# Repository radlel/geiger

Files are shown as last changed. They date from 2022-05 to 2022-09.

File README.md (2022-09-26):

# Geiger-Muller counter

This project describes complete process of designing and constructing
Geiger-Muller counter device.

## Counter final form:

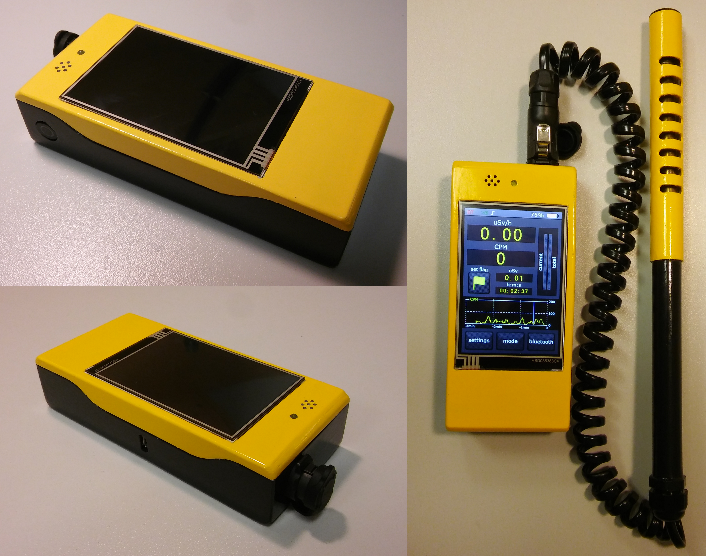
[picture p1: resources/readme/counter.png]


## Features:
- Current radiation measurement
- Background radiation measurement
- Total absorbed radiation dose measurement
- High radiation levels warnings
- 3.5" touch screen
- Advanced data presentation
- Dedicated android application for storing measured data
- Bluetooth connection
- 3D printed cover
- Measurements modes
- LED and buzzer notifications
- Li-ion cell

## Scientific background
A Geiger–Müller counter is device used for detecting and measuring ionizing radiation.
It detects radiation such as alpha particles, beta particles, and gamma rays.
Detection is possible thanks to ionization effect produced in a Geiger–Müller tube.



Between anode (_A_) and cathode (_K_) there is high voltage applied (typically 400–900V),
which enables tube operation. Tube is filled with an inert gas such as helium, neon,
or argon at low pressure. When a particle or photon of incident radiation goes through the tube,
it makes the gas conductive by ionization and the tube briefly conducts electrical charge.
The ionization is considerably amplified within the tube by the Townsend discharge effect to
produce an easily measured detection pulse. Pulses are counted by electronic device and
recalculated to radiation in Sv/Rem, according to tube characteristic.

## Data presented on Counter screen:

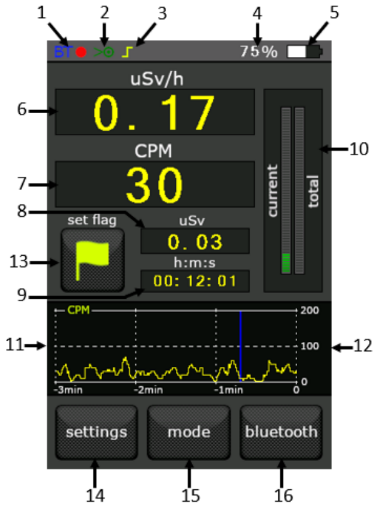
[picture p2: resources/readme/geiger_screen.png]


1. Bluetooth connection status
2. Touch screen status
3. Background radiation subtraction status
4. Screen brightness
5. Battery level
6. Radiation level (uSv/h, uRem/h)
7. Counts per minute (CPM)
8. Total dose absorbed (uSv, uRem)
9. Measurement time
10. Radiation level warning bars
11. CPM chart from last 3 minutes
12. Adjustable CPM chart range
13. Button for adding markers to measurement
14. Button opening settings submenu
15. Button opening measurement modes submenu
16. Button opening bluetooth connection submenu

## Electronics

### _Geiger-Muller tube amplification_
The most crucial circuit of whole device is detection and amplification of
Geiger-Muller tube pulses. Detection is performed by tube SBM-20.
Between its anode and cathode there is high 400V voltage applied.
Pulses amplification is done by two bipolar transistors BC547B.
Output signal is connected to uC input pin with interrupts handling implemented.
Additionally, every pulse is notified by LED and buzzer connected to the circuit.

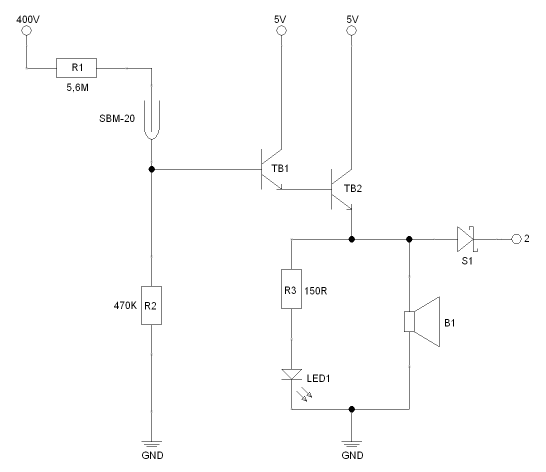
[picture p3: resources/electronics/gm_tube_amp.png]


### _Power supply_
Device is powered by Li-ion cell Panasonic NCR 18650B if capacity 3400mAh.
For charging and cell protection it is used circuit TP4056.
To ensure stable voltage for the device there is also DC-DC converter
used which generates output voltage 5V regardless battery voltage.
As mentioned already, Geiger-Muller tube requires 400V for proper operation.
For this reason there is another DC-DC transformer used which accepts 5V
as input and generates 400V output.

There are other electronic elements and circuits integrated into device.
The full electrical diagram is available _[here](resources/electronics/ee_complete.png)_.

## Atmega software
Main Counter logic is written in C based Arduino language.
Used libraries:
- Arduino
- Nextion
- SoftwareSerial

Interrupts are used to detect Geiger-Muller tube pulses as well as button press.

In _loop()_ function there is periodic execution of:
- Radiation measurement and calculations
- Touch screen actions handling
- Power button actions handling
- Bluetooth connection and communication
- Battery voltage monitoring
- Warnings handling

Communication with touch screen is carried out via UART. Data to be displayed is sent periodically. Touch screen actions are obtained with use of polling mechanism. Every actions has its own unique id which triggers certain action in uC.

Complete Atmega source code is available _[here](Atmega/Atmega_328P.ino)_.

## Geiger RL2018PI application
This Android application was created in Android Studio/Java.

It's main task is to establish connection with Geiger-Muller counter via Bluetooth, collect measurement data
and generate output .xls file for later analysis.

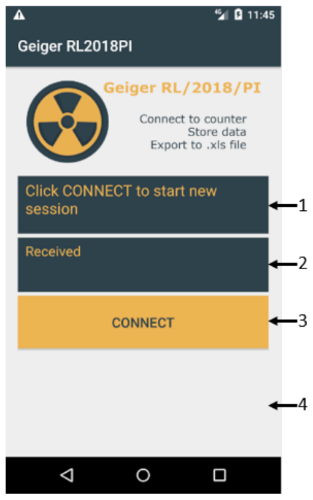
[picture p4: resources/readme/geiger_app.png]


1. Connection status
2. Data received from Geiger-Muller counter
3. Button to connect/disconnect 
4. List of paired bluetooth devices

Source code is available _[here](Android/Mobile.apk)_.

## Device cover
Main device cover was designed in SolidWorks and then printed using 3D printer.
Cover was split into two parts - bottom and top. The design included holes for Geiger-Muller tube cable,
charging cable, buzzer, LED and power button. Also, supports for internal elements were added.

After assembling Counter, bottom and top cover parts are held together by hooks.

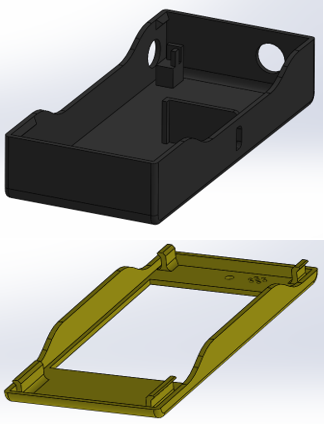
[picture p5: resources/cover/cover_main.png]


Device cover was smoothed and pained for yellow and dark grey colors.

Geiger-Muller tube SBM-20 was placed in separate cover made from two PVC pipes. For better handling covers were
connected by spiral cable. Project files and more photos are available _[here](cover)_ and _[here](resources/cover)_.

## Counter characteristics
_TODO_

## License
[MIT](https://choosealicense.com/licenses/mit/)

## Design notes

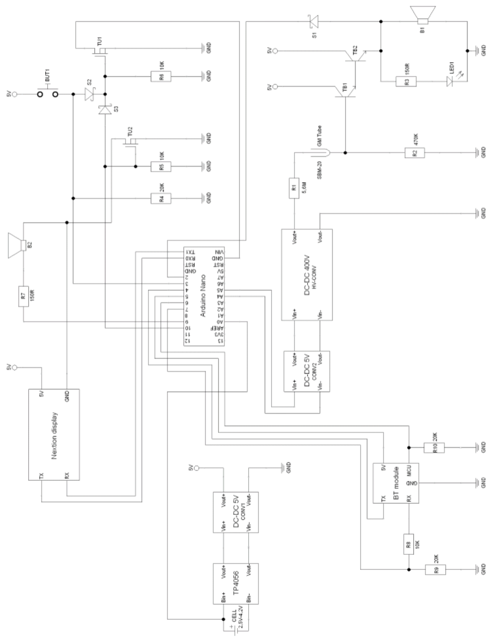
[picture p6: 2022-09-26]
resources/electronics/ee_complete.png

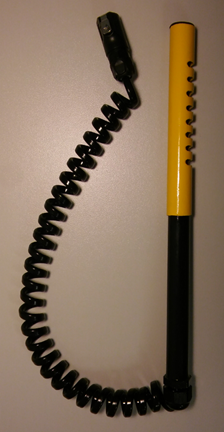
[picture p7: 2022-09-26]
resources/cover/cover_tube.png

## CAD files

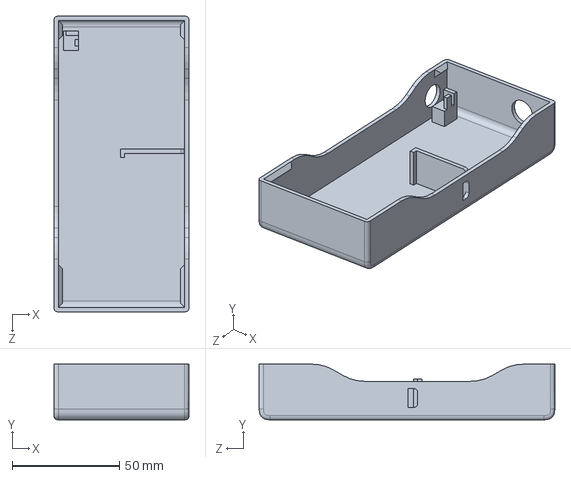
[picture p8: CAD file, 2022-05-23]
cover/Part_bottom.SLDPRT
63.0 x 26.0 x 138.0 mm

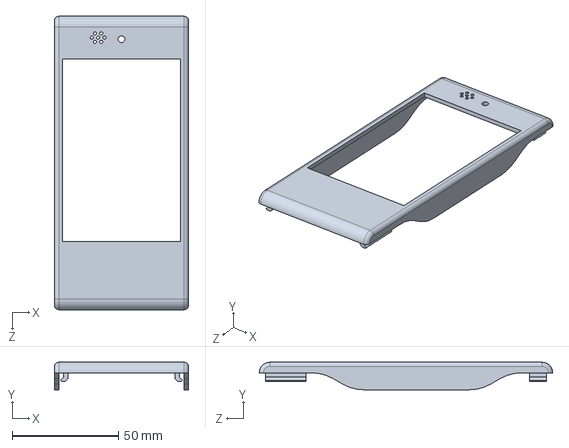
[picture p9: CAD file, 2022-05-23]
cover/Part_top.SLDPRT
63.0 x 13.0 x 138.0 mm

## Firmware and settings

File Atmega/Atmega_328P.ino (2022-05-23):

#include "Arduino.h"
#include "Nextion.h"
#include "SoftwareSerial.h"


#define DET 2
#define BUT 3
#define bluetoothP 5
#define PIR 6
#define POW 10
#define ALARM_PIN 9
#define CONV_GND 18
#define CONV_VCC 19
#define CEL A0

#define TB_S 6
#define CPMtouSvpH 0.0057
#define COUNTtouSv (CPMtouSvpH / 60)
#define TON 1150
#define TOF 3000


enum alarm_source {
  BT_CON_BROKEN,
  LOW_BATTERY,
  HIGH_CURR_RADIATION
  HIGH_TOTAL_RADIATION
};


volatile unsigned short ssc = 0;
unsigned short tab[TB_S] = {0};
unsigned short t_i = 0;
unsigned long tt;
unsigned long t_sec = 0;
unsigned long CPM = 0;
unsigned long uSv = 0;
unsigned short plot_rg = 200;
unsigned long background_val = 0;
unsigned long source_val = 0;
long measure_result = -1;
String flag_name = "";
SoftwareSerial bluetoothS (4, 7);

NexProgressBar ncl (0, 8, "j2");
NexVariable r1 (0, 22, "R1");
NexVariable r2 (0, 23, "R2");
NexVariable r3 (0, 24, "R3");
NexVariable r4 (0, 25, "R4");
NexVariable r5 (0, 26, "R5");
NexVariable r6 (0, 27, "R6");
NexVariable y1 (0, 36, "y1");
NexVariable y2 (0, 37, "y2");
NexVariable t4 (0, 54, "t4");
NexVariable t5 (0, 54, "t5");
NexVariable nex_flag (0, 56, "flag_str");
NexVariable touch (0, 38, "touch");
NexVariable help (0, 49, "help");

boolean start_patr_2 = true;
boolean bluetooth = false;
boolean pair = false;
boolean bt_finish = false;
boolean rem = false;
boolean background = false;
boolean measure = false;
boolean reset = false;
boolean alarm = false;
boolean usv_range_end = false;

volatile boolean button = false;


void setup() {
	pinMode(BUT, INPUT);
	pinMode(POW, OUTPUT);
	pinMode(bluetoothP, OUTPUT);
	pinMode(PIR, INPUT);
	pinMode(ALARM_PIN, OUTPUT);

	pinMode(CONV_GND, OUTPUT);
	pinMode(CONV_VCC, OUTPUT);

	attachInterrupt(0, excDet, RISING);
	attachInterrupt(1, excBut, RISING);
	nexInit();
	bluetoothS.begin(9600);

	delay(TON);
	digitalWrite(POW, HIGH);
	digitalWrite(CONV_GND, LOW);
	digitalWrite(CONV_VCC, HIGH);
	start_p1();
}

void loop() {
	check_nex_touch();
	if(!reset) proc_and_print_results();
	if(bluetooth) bluetooth_send();
	if(bluetooth) bluetooth_read();
	if(pair) if_paired();
	if(measure) measure();
	if(button) check_button();
	set_cell_level();
	if(alarm) alarm_sound();
	if(reset) reset();
}


void excDet() { ssc ++; }

void excBut() { if(t_sec > 0 && !reset) button = true; }


void start_p1() {
	tt = millis();
	while(t_i < TB_S - 1) {
		if(millis() - tt >= 1000) {
			tab[t_i] = ssc;
			ssc = 0;
			tt = millis();
			t_i ++;
			if(t_i == 1) ncl.setValue(map(no_bigger_than(analogRead(CEL), 860), 512, 860, 0, 100));
		}
	}
	tt = millis();
}

void start_p2() {
	sendCommand("sys0=1");
	sendCommand("tsw 255,1");
	sendCommand("plot.en=1");
	sendCommand("p2.pic=56");
	start_patr_2 = false;
}

void reset() {
	for(int i = 0; i < TB_S; i++) tab[i] = 0;
	ssc = 0;
	t_i = 0;
	t_sec = 0;
	CPM = 0;
	uSv = 0;
	plot_rg = 200;
	background_val = 0;
	source_val = 0;
	measure_result = -1;
	start_patr_2 = true;
	bluetooth = false;
	digitalWrite(bluetoothP, LOW);
	pair = false;
	rem = false;
	background = false;
	measure = false;

	start_p1();
	reset = false;
}

void check_nex_touch() {
	static unsigned long ttl = millis();
	char flag_buf[31] = {0};

	if(millis() - ttl >= 100) {
		ttl = millis();
		uint32_t n;
		touch.getValue(&n);

		switch(n) {
		case 0:		
			if(measure_result != -1) measure_result = -1;
			break;
		case 1:		
			rem = true;
			if(background_val > 0) proc_and_set(background_val, t4, "t4");
			if(source_val > 0 && source_val > background_val && background) proc_and_set(source_val - background_val, t5, "t5");
			else if(source_val > 0 && source_val <= background_val && background) t5.setText("0.00");
			else if(source_val > 0 && !background) proc_and_set(source_val, t5, "t5");
			sendCommand("click func,1");
			break;
		case 2:		
			rem = false;
			if(background_val > 0) proc_and_set(background_val, t4, "t4");
			if(source_val > 0 && source_val > background_val && background) proc_and_set(source_val - background_val, t5, "t5");
			else if(source_val > 0 && source_val <= background_val && background) t5.setText("0.00");
			else if(source_val > 0 && !background) proc_and_set(source_val, t5, "t5");
			sendCommand("click func,1");
			break;
		case 9:		
			reset = true;
			sendCommand("rest");
			break;
		case 11:	
			measurement(&background_val, n);
			break;
		case 12:	
			measurement(&source_val, n);
			break;
		case 18:	
			background = true;
			if(source_val > 0 && source_val > background_val) proc_and_set(source_val - background_val, t5, "t5");
			else if(source_val > 0 && source_val <= background_val) t5.setText("0.00");
			sendCommand("click func,1");
			break;
		case 19:	
			background = false;
			if(source_val > 0) proc_and_set(source_val, t5, "t5");
			sendCommand("click func,1");
			break;
		case 31:	
			digitalWrite(bluetoothP, HIGH);
			pair = true;
			sendCommand("click func,1");
			break;
		case 32:	
			bt_finish = true;
			digitalWrite(bluetoothP, LOW);
			bluetooth = false;
			sendCommand("click func,1");
			break;
		case 33:	
			bluetooth = false;
			pair = false;
			digitalWrite(bluetoothP, LOW);
			sendCommand("help.val=32");
			sendCommand("click func,1");
			break;
		case 41:	
			memset(flag_buf, 0, sizeof(flag_buf));
			nex_flag.getText(flag_buf, sizeof(flag_buf));
			flag_name = String(flag_buf);
			if(flag_name != "") sendCommand("click func,1");
			break;
		case 100:	
			plot_rg = 100;
			sendCommand("click func,1");
			break;
		case 200:
			plot_rg = 200;
			sendCommand("click func,1");
			break;
		case 500:
			plot_rg = 500;
			sendCommand("click func,1");
			break;
		case 1000:
			plot_rg = 1000;
			sendCommand("click func,1");
			break;
		case 2000:
			plot_rg = 2000;
			sendCommand("click func,1");
			break;
		case 5000:
			plot_rg = 5000;
			sendCommand("click func,1");
			break;
		case 10000:
			plot_rg = 10000;
			sendCommand("click func,1");
			break;
		}
	}
}

void proc_and_print_results() {
	if(millis() - tt >= 1000) {
		unsigned short ssc_t;

		tab[t_i] = ssc_t = ssc;
		ssc = 0;
		tt = millis();
		if(t_i < TB_S - 1) t_i ++;
		else t_i = 0;

		CPM = 0;
		for(int i = 0; i < TB_S; i++) CPM += tab[i];
		CPM *= (60 / TB_S);
		long dif = 0;
		if(background) {
			dif = CPM - background_val;
			if(dif < 0) dif = 0;
			r2.setValue(dif);
		}
		else r2.setValue(CPM);

		if(background) proc_and_set(background_val >= CPM ? 0 : CPM - background_val, r1, "r1");
		else proc_and_set(CPM, r1, "r1");

		static boolean too_big_uSvph = false;
		if(CPM * CPMtouSvpH >= 1.17 && !too_big_uSvph) {
			alarm_show(3);
			too_big_uSvph = true;
		}

		if(too_big_uSvph && CPM * CPMtouSvpH < 1.17) {
			sendCommand("A3.val=2");
			too_big_uSvph = false;
		}

		if(!usv_range_end) {
			uSv += ssc_t;
			proc_and_set(uSv, r3, "r3");
		}

		static boolean too_big_uSv = false;
		if(uSv * COUNTtouSv >= 9.32  && !too_big_uSv) {
			too_big_uSv = true;
			alarm_show(4);
		}

		r4.setValue(t_sec);
		t_sec ++;

		if(CPM * CPMtouSvpH <= 0.39) r5.setValue(int(map_f(CPM * CPMtouSvpH, 0.0, 0.39, 0, 44)));
		else 			r5.setValue(int(map_f(no_bigger_than(CPM * CPMtouSvpH, 5.0), 0.39, 5.0, 44, 100)));

		if(uSv * COUNTtouSv <= 9.32) r6.setValue(int(map_f(uSv * COUNTtouSv, 0, 9.32, 0, 61)));
		else 		    r6.setValue(int(map_f(no_bigger_than_f(uSv * COUNTtouSv, 27.96), 9.32, 27.96, 61, 100)));

		static boolean ch = true;
		if(ch) y1.setValue(map(no_bigger_than(CPM, plot_rg), 0, plot_rg, 1, 80));
		else   y2.setValue(map(no_bigger_than(CPM, plot_rg), 0, plot_rg, 1, 80));
		ch = !ch;

		if(start_patr_2) start_p2();
	}
}

void proc_and_set(unsigned long value, NexVariable nt, String nex_name) {
	char buf[10] = {0};
	String str = "";

	if(nex_name == "r1") {
		if (!rem || (rem && value * CPMtouSvpH < 100.0)) str = String(double(value * CPMtouSvpH * (rem ? 100 : 1)));
		else str = String(long(value * CPMtouSvpH * 100 + 0.5));
	} else if(nex_name == "r3") {
		if(uSv * COUNTtouSv >= 100000.0) {
			str = ">100mSv";
			usv_range_end = true;
		} else if(rem && value * COUNTtouSv >= 1000.0) str = String(long(value * COUNTtouSv * 100 + 0.5));
		else str = String(double(value * COUNTtouSv * (rem ? 100 : 1)));
	} else if(nex_name == "t4" || nex_name == "t5") {
		str = String(double(value * CPMtouSvpH * (rem ? 100 : 1)));
	}

	str.toCharArray(buf, sizeof(buf), 0);
	nt.setText(buf);
}

void measure() {
	static boolean start = true;
	static unsigned long temp = 0;
	static unsigned long ttl1, ttl2;
	if(start) {
		ttl1 = ttl2 = t_sec;
		start = false;
		temp = 0;
	}

	if(t_sec - ttl1 == TB_S ) {
		for(int i = 0; i < TB_S; i++) temp += tab[i];
		ttl1 = t_sec;
	}

	if(t_sec - ttl2 >= 600) {
		measure_result = temp / 10;
		measure = false;
		start = true;
	}
}

void measurement(unsigned long *v, uint32_t n) {
	if(measure == false && measure_result == -1) measure = true;
	if(measure_result > -1) {
		*v = measure_result;
		sendCommand("click func,1");
		if	    (n == 12 && source_val > background_val && background) proc_and_set(source_val - background_val, t5, "t5");
		else if (n == 12 && source_val <= background_val && background) t5.setText("0.00");
		else if (n == 12 && !background) proc_and_set(source_val, t5, "t5");
		else if (n == 11) {
			proc_and_set(background_val, t4, "t4");
			if(background && source_val > 0 && source_val > background_val) proc_and_set(source_val - background_val, t5, "t5");
			else if(background && source_val > 0 && source_val <= background_val) t5.setText("0.00");
		}
		measure_result = -2;
	}
}

void bluetooth_send() {
	static unsigned long temp = 0;
	if(temp != t_sec) {
		bluetoothS.println(String(t_sec - 1) + "," + String(t_i > 0 ? tab[t_i - 1] : tab[TB_S - 1]) + "," + flag_name + ",");
		temp = t_sec;
		if(flag_name != "") flag_name = "";
	}
}

void if_paired() {
	static boolean paired = false;
	if(digitalRead(PIR) && !paired) {
		sendCommand("help.val=5555");
		sendCommand("click func,1");
		bluetooth = true;
		paired = true;
	}
	if(!digitalRead(PIR) && paired) {
		sendCommand("help.val=32");
		sendCommand("click func,1");
		digitalWrite(bluetoothP, LOW);
		bluetooth = false;
		pair = false;

		if(!bt_finish) alarm_show(1);
		else bt_finish = false;

		paired = false;
	}
}

void bluetooth_read() { if (bluetoothS.available() > 0 && bluetoothS.read() == 'x') bt_finish = true; }

void set_cell_level() {
	static boolean setCL = true;
	if(t_sec % 60 == 0 && setCL) {
		short temp = map(no_bigger_than(analogRead(CEL), 860), 512, 860, 0, 100);
		ncl.setValue(temp);
		setCL = false;

		static bool under_3V = false;
		if(temp <= 30 && !under_3V) {
			alarm_show(2);
			under_3V = true;
		}
		if(under_3V && temp > 30) {
			sendCommand("j2.ppic=12");
			under_3V = false;
		}
	}
	if(t_sec % 60 != 0) setCL = true;
}

void check_button() {
	static unsigned long ttl = 0;
	if(!digitalRead(BUT)) {
		sendCommand("help.val=4321");
		sendCommand("click func,1");
		button = false;
		ttl = 0;
	} else {
		if(millis() - ttl >= TOF + 2000) ttl = millis();
		if(millis() - ttl >= TOF) {
			digitalWrite(POW, LOW);
			digitalWrite(CONV_VCC, LOW);
		}
	}
}

void alarm_sound() {
	static unsigned long ttl = 0;
	if(millis() - ttl >= 3500) ttl = millis();

	if(millis() - ttl <= 800) digitalWrite(ALARM_PIN, HIGH);
	else if(millis() - ttl > 800 && millis() - ttl <= 1600) digitalWrite(ALARM_PIN, LOW);
	else if(millis() - ttl > 1600 && millis() - ttl <= 2400) digitalWrite(ALARM_PIN, HIGH);

	if(millis() - ttl >= 2400) {
		digitalWrite(ALARM_PIN, LOW);
		alarm = false;
	}
}

void alarm_show(short n) {
	switch(n) {
	case BT_CON_BROKEN:
		sendCommand("A1.val=1");
		break;
	case LOW_BATTERY:
		sendCommand("j2.ppic=71");
		break;
	case HIGH_CURR_RADIATION:
		sendCommand("A3.val=1");
		break;
	case HIGH_TOTAL_RADIATION:
		sendCommand("A4.val=1");
		break;
	}
	alarm = true;
}

double map_f(double v, double in_min, double in_max, double out_min, double out_max) { return (v - in_min) * (out_max - out_min) / (in_max - in_min) + out_min; }

unsigned short no_bigger_than(unsigned short val, unsigned short max) { return ((val > max) ? max : val); }

double no_bigger_than_f(double val, double max) { return ((val > max) ? max : val); }
